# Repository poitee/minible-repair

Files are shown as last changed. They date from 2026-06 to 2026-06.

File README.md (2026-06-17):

# Mooltipass Mini BLE repair project

Community guides and printable parts to extend the life of a Mini BLE.

## Contents

| Path | Description |
|---|---|
| [battery/BOM.md](battery/BOM.md) | Replacement cell specifications and sourcing notes |
| [battery/replacement.md](battery/replacement.md) | Step-by-step battery swap procedure |
| [case/minible-shell.scad](case/minible-shell.scad) | Parametric service shell (OpenSCAD) |
| [case/stl/](case/stl/) | **Print-ready STL files** (top, bottom, battery door) |
| [case/README.md](case/README.md) | How to export STLs and assemble the shell |
| [case/print-settings.md](case/print-settings.md) | Suggested slicer settings |
| [docs/dimensions.md](docs/dimensions.md) | KiCad-derived mechanical reference |
| [docs/teardown.md](docs/teardown.md) | Case opening notes and internal layout |
| [tools/extract_kicad_dims.py](tools/extract_kicad_dims.py) | Regenerate feature coordinates from KiCad |

## Quick links

**Replace the battery** → start with [battery/BOM.md](battery/BOM.md)

**Print a service shell** → [case/README.md](case/README.md)

**Open the factory case** → [docs/teardown.md](docs/teardown.md)

## Important safety notes

- The Mini BLE uses a **NiMH** cell, not LiPo. Do not install a lithium cell.
- The stock cell is soldered to the PCB. Replacement requires soldering skills.
- Opening the factory aluminum shell may damage it. Treat this project as a **repair path**, not a drop-in factory replacement.
- You are responsible for safe handling of batteries and ESD-sensitive electronics.

## Device reference dimensions

Published external size: **89.0 × 35.5 × 12.5 mm** (L × W × H).

PCB outline from [minible_hw](https://github.com/mooltipass/minible_hw): **74.8 × 31.2 mm**.

Battery: **2/3 AAA NiMH**, ~300 mAh (`BAT_TWOTHIRD_AAA`).

Full coordinate table: [docs/dimensions.md](docs/dimensions.md).

## Status

Community draft — fit has not been validated on physical hardware yet. If you print the shell or complete a battery swap, please share caliper measurements and photos.

## Contributing

See [CONTRIBUTING.md](CONTRIBUTING.md).

## License

MIT — see [LICENSE](LICENSE).

## Related upstream projects

- [mooltipass/minible](https://github.com/mooltipass/minible) — firmware
- [mooltipass/minible_hw](https://github.com/mooltipass/minible_hw) — hardware design files
- [mooltipass/moolticute](https://github.com/mooltipass/moolticute) — desktop companion

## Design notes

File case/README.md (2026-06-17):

# Case parts

Parametric OpenSCAD shell for servicing a Mini BLE after the factory aluminum case is opened or damaged.

## Files

| File | Description |
|---|---|
| `minible-shell.scad` | Source model — edit parameters here |
| `export-stl.sh` | Headless STL export |
| `stl/` | Generated meshes (after export) |
| `print-settings.md` | Suggested slicer settings |

## Quick start

**Pre-built STLs** are in [`case/stl/`](stl/) — ready to slice.

To regenerate after editing `minible-shell.scad` or `tools/generate_stl.py`:

```bash
pip3 install -r tools/requirements.txt
./case/export-stl.sh
```

Or only:

```bash
python3 tools/generate_stl.py
```

OpenSCAD is optional (see `minible-shell.scad` for parametric edits); STL export uses Python + [trimesh](https://github.com/mikedh/trimesh).

This writes:

- `case/stl/minible-shell-top.stl` — display face + scroll wheel bore
- `case/stl/minible-shell-bottom.stl` — USB-C, smartcard slot, battery pocket
- `case/stl/minible-battery-door.stl` — optional cover for battery pocket

## Assembly

1. Print top and bottom shells (see `print-settings.md`).
2. Dry-fit the PCB without the battery.
3. Route the OLED flex cable before closing the shell.
4. Join halves with four M2 screws through J1/J2 standoff posts (length depends on print — start with 8–10 mm).
5. Optionally tape or screw the battery door over the access pocket.

## Tuning fit

Open `minible-shell.scad` and adjust:

- `clearance` — global PCB pocket tolerance (default 0.4 mm)
- `usb_open_*` — USB cutout size
- `wheel_bore_d` — scroll wheel clearance
- `battery_door_*` — under-cell access opening

After changing parameters tied to KiCad, update `docs/dimensions.md` and note your caliper measurements in the pull request.

## Orientation preview

In OpenSCAD, set `part = "both"` to preview top + bottom + battery door layouts side by side.

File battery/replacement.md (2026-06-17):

# Battery replacement procedure

## Before you start

- Read [BOM.md](BOM.md) and confirm you have a **tagged 2/3 AAA NiMH** cell.
- Export your credentials from Moolticute if you have not recently backed up.
- Work on an ESD-safe surface.
- Expect to **open or replace the outer shell** — see [../docs/teardown.md](../docs/teardown.md).

## Discharge handling

If the old cell still holds charge, avoid shorting the tabs. Insulate removed cell terminals with tape.

## Removal

1. Open the device enclosure and expose the main PCB.
2. Note pad polarity — photograph the original orientation.
3. Apply flux to both battery pads.
4. Heat each pad in turn and lift the cell free with minimal force on the tabs.
5. Remove residual solder from pads if needed so the new tabs sit flat.

## Installation

1. Match the **positive tab** to the pad marked `BAT+` on the [PSU schematic](https://github.com/mooltipass/minible_hw/blob/master/main_board/mini_ble_psu.sch).
2. Tack one tab, verify alignment, then solder the second tab.
3. Avoid excessive heat — work quickly and let the cell cool between attempts.
4. Visually inspect joints under good light.

## Reassembly and validation

1. Route the OLED flex cable carefully — it is easy to damage ([minible_hw#4](https://github.com/mooltipass/minible_hw/issues/4)).
2. Reinstall the PCB in your shell (factory aluminum or [printed service shell](../case/minible-shell.scad)).
3. Connect USB:
   - Device should enumerate normally.
   - Leave on charge until the firmware reports a full state.
4. Unplug USB and confirm:
   - Power-on via scroll wheel click
   - Stable operation for at least several minutes
   - Reasonable battery indicator behavior

## Troubleshooting

| Symptom | Likely cause |
|---|---|
| Works on USB only | Weak/counterfeit cell, cold solder joint, reversed polarity |
| Rapid shutdown after unplug | Cell not actually charged, high self-discharge cell |
| Overheating on charge | Wrong chemistry installed — **stop and disconnect** |

## Firmware notes

The Mini BLE firmware includes a custom NiMH charging routine. There is no documented “battery pairing” or anti-replacement lock — failures are almost always hardware-related.

For persistent issues after verifying a known-good cell, open a discussion in this repo with photos of the solder joints (not your credentials).

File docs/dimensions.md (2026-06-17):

# Mechanical dimensions

Values below are derived from [mooltipass/minible_hw](https://github.com/mooltipass/minible_hw) `main_board/mini_ble.kicad_pcb` and published retail specifications.

Regenerate `dimensions.json`:

```bash
python3 tools/update_dimensions.py
```

## Envelope

| Item | mm |
|---|-----|
| Retail case (L × W × H) | 89.0 × 35.5 × 12.5 |
| Main PCB (L × W) | 74.8 × 31.2 |
| PCB inset margin (X / Y) | 7.1 / 2.15 |

## Coordinate system (case)

- Origin: bottom-left-back corner
- **+X** → scroll wheel end
- **+Y** → smartcard edge
- **+Z** → display face

## Feature positions (case coordinates)

| Feature | X | Y | Notes |
|---|---|---|---|
| USB-C | 72.9 | 5.35 | GT-USB-7010 receptacle |
| Scroll wheel | 78.4 | 17.75 | SRBE210200 |
| OLED center | 41.4 | 17.75 | ~52 × 14 mm window (active area — verify) |
| Smartcard | 19.0 | 29.3 | Slot on +Y edge |
| Battery BT1 | 7.4 | 17.75 | 2/3 AAA NiMH, soldered |
| Mount J1 | 9.6 | 3.75 | M1.4 |
| Mount J2 | 9.6 | 31.75 | M1.4 |

## Battery cell

| Property | Value |
|---|---|
| Footprint | `BAT_TWOTHIRD_AAA` |
| Chemistry | NiMH |
| Capacity | ~300 mAh |
| Pad spacing | 20.6 mm center-to-center |

## Still verify on hardware

- PCB stack height (`pcb_h` in OpenSCAD, default 6.0 mm)
- OLED visible area vs. bezel overlap
- USB-C recess depth for your cable shell
- Factory aluminum shell internal ribs (not modeled in KiCad)

## References

- [FCC internal photos (MBLE1)](https://fccid.io/2AYPT-MBLE1/Internal-Photos/Internal-Photos-5088688)
- [minible_hw#4 — battery disconnect switch request](https://github.com/mooltipass/minible_hw/issues/4)

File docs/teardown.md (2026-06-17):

# Teardown notes

## Factory enclosure

The retail Mini BLE uses a **brushed aluminum** shell approximately **89 × 35.5 × 12.5 mm**. The factory assembly is not designed for end-user service. Expect:

- Adhesive or tight snap fits
- Risk of cosmetic damage when opening
- No standard screws on most units

Community contributors should document their opening method here once validated. If you succeed with a repeatable technique, add photos via pull request.

## Internal layout (from open hardware files)

Reference repository: [mooltipass/minible_hw](https://github.com/mooltipass/minible_hw)

| Item | Notes |
|---|---|
| Main PCB outline | 74.8 × 31.2 mm (Edge.Cuts bounding box) |
| Battery `BT1` | 2/3 AAA NiMH, soldered (`BAT_TWOTHIRD_AAA`) |
| Display | OLED module with fragile flex cable |
| USB-C | Board edge connector |
| Scroll wheel | Mechanical assembly on front face |
| Smartcard slot | End of device |

## FCC internal photos

Stephan Electronics filed internal photos for model **MBLE1**:

https://fccid.io/2AYPT-MBLE1/Internal-Photos/Internal-Photos-5088688

Use these photos together with the KiCad PCB to confirm component keep-out zones before printing a service shell.

## Recommended service approach

1. Open or sacrifice the factory shell once.
2. Take **caliper measurements** of:
   - PCB-to-shell clearance (top/bottom/sides)
   - Display active area and bezel overlap
   - USB-C port centerline and panel thickness
   - Scroll wheel bore diameter and exposed height
3. Compare against [dimensions.md](dimensions.md) and tune [minible-shell.scad](../case/minible-shell.scad).
4. Install the PCB in the printed **service shell** for future battery access.

## Opening techniques (community draft)

The stock shell is aluminum and not designed for user service. Approaches reported in similar devices:

| Method | Risk | Notes |
|---|---|---|
| Plastic spudger along seam | Cosmetic scratches | Work slowly around the perimeter |
| Heat gun + isopropyl on adhesive | Warping / burn risk | Low heat only; keep away from battery |
| Sacrifice rear panel | Lose waterproofing | Acceptable if moving to printed shell |

> **We need community validation.** If you successfully open a unit, please document your method with photos in a pull request.

## Assembly orientation

When viewing the device with the **display facing up** and the **scroll wheel to your right**:

- USB-C is on the bottom edge near the wheel end
- Smartcard slot is on the top edge near the battery end
- Battery cell sits under the left end of the PCB

## Battery service constraint

The stock design routes battery replacement through **desoldering** because there is no inline disconnect switch ([minible_hw#4](https://github.com/mooltipass/minible_hw/issues/4)). Plan for full PCB removal or a shell that allows bottom access.

## ESD and cleanliness

The secure MCU and smartcard interface are ESD-sensitive. Avoid metal tools near powered flex cables.

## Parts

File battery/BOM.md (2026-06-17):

# Mini BLE replacement battery — BOM

## Required cell

| Property | Value | Source |
|---|---|---|
| Chemistry | **NiMH** | [minible_hw](https://github.com/mooltipass/minible_hw) schematic (`BT1`) |
| Form factor | **2/3 AAA** | KiCad footprint `BAT_TWOTHIRD_AAA` |
| Nominal capacity | **~300 mAh** | [product specs](https://www.themooltipass.com) |
| Terminals | Solder tabs | Stock cell is through-hole soldered to PCB |

### Pad spacing (from KiCad footprint)

- Center-to-center between pads: **20.6 mm**
- Pad size: 4 × 3 mm oval holes

### Typical 2/3 AAA NiMH dimensions

| Dimension | Typical range |
|---|---|
| Diameter | 10.0 – 10.5 mm |
| Height (without tabs) | 30.0 – 31.0 mm |

Always measure your replacement cell before soldering.

## What **not** to use

- **LiPo / Li-ion cells** — charging circuitry implements a custom **NiMH** algorithm in firmware.
- **NiCd** — different charge profile; not validated on this hardware.
- Cells without reliable capacity ratings or unknown age (see [minible#422](https://github.com/mooltipass/minible/issues/422)).

## Example part categories

Search distributors for:

- `2/3 AAA NiMH 300mAh solder tabs`
- `2/3 AAA NiMH tagged`

Brands commonly used in tagged NiMH packs: Tenergy, Powerex, generic industrial tagged cells.

> Supplier links intentionally omitted — availability varies by region. Validate diameter and tab orientation against the original cell before ordering multiple units.

## Tools and consumables

- Temperature-controlled soldering iron (fine tip)
- Flux and lead-free solder
- Kapton tape
- ESD mat / wrist strap
- Plastic spudgers
- Multimeter (verify polarity and idle voltage after install)

## After installation

1. Inspect for solder bridges on battery pads.
2. Reassemble the device.
3. Connect USB and confirm the device boots.
4. In Moolticute, run **battery reconditioning** if available for your firmware bundle.
5. Disconnect USB and verify the device runs on battery power.

If the device only works on USB, the cell may be dead, reversed, or poorly soldered — not a firmware “security lock” ([#422](https://github.com/mooltipass/minible/issues/422)).

## Future hardware improvement

Upstream feature request: inline battery disconnect switch — [minible_hw#4](https://github.com/mooltipass/minible_hw/issues/4).

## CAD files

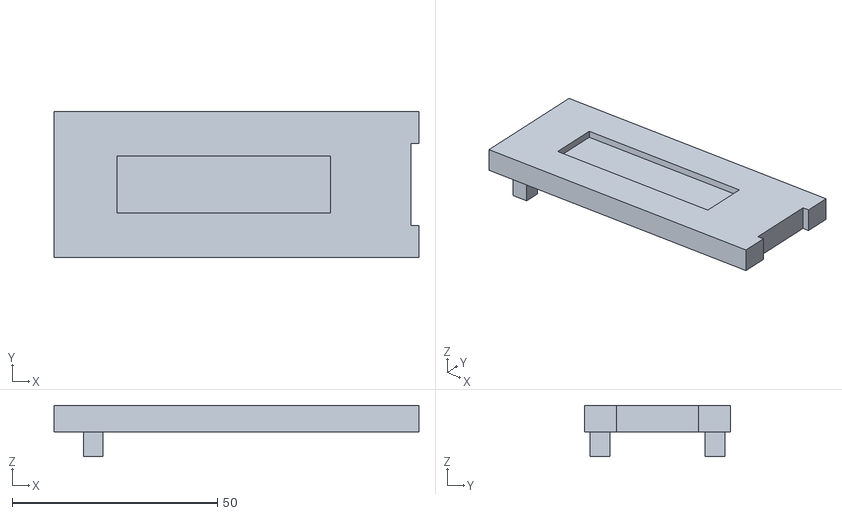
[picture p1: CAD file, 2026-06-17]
case/stl/minible-shell-top.stl
89.0 x 35.5 x 12.5

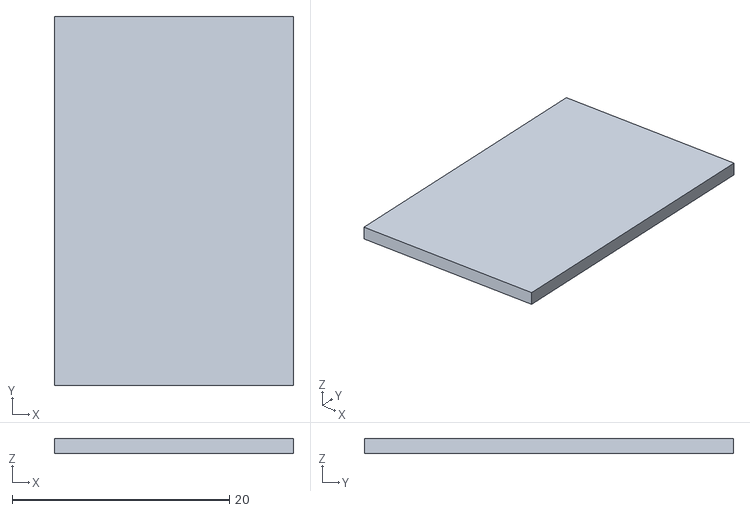
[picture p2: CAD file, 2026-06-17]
case/stl/minible-battery-door.stl
22.0 x 34.0 x 1.40

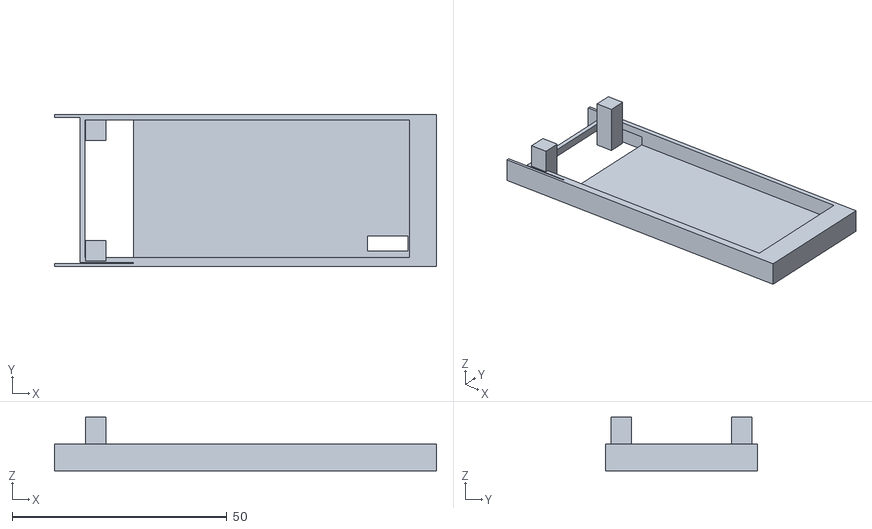
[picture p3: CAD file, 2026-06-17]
case/stl/minible-shell-bottom.stl
89.0 x 35.5 x 12.5

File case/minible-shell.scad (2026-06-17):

// Mooltipass Mini BLE — service shell (two-part clam shell)
// Coordinate system: origin at bottom-left-back corner of the case.
//   +X = toward scroll wheel end (89 mm)
//   +Y = toward smartcard edge (35.5 mm)
//   +Z = toward display face (12.5 mm)
//
// Dimensions derived from minible_hw KiCad (see docs/dimensions.md).
// Run: ./case/export-stl.sh

part = "both";          // "front" | "back" | "both" | "battery_door"

// --- case envelope ---
case_l = 89.0;
case_w = 35.5;
case_h = 12.5;
wall = 1.8;
clearance = 0.4;
corner_r = 3.0;

// --- PCB pocket ---
pcb_l = 74.8;
pcb_w = 31.2;
pcb_h = 6.0;            // verify stack height on hardware
margin_x = (case_l - pcb_l) / 2;   // 7.1
margin_y = (case_w - pcb_w) / 2;   // 2.15

// --- feature positions (case coords, mm) ---
usb_x = 72.9;
usb_y = 5.35;
usb_open_w = 9.5;
usb_open_h = 3.5;

wheel_x = 78.4;
wheel_y = 17.75;
wheel_bore_d = 20.0;

oled_cx = 41.4;         // approx. center of 52 mm active area
oled_cy = 17.75;
oled_w = 52.0;
oled_h = 14.0;

card_x = 4.0;
card_y = 29.3;
card_slot_w = 24.0;
card_slot_h = 1.4;

battery_cx = 7.4;
battery_cy = 17.75;
battery_door_w = 22.0;
battery_door_h = 34.0;

mount_j1 = [9.6, 3.75];
mount_j2 = [9.6, 31.75];
mount_d = 1.6;          // M1.4 screw clearance

lip_depth = 2.0;
lip_inset = 1.2;
split_gap = 0.25;
screw_post_d = 4.8;

inner_l = pcb_l + 2 * clearance;
inner_w = pcb_w + 2 * clearance;
inner_h = pcb_h + clearance;

module rounded_box(l, w, h, r) {
    // Simple chamfered box — avoids heavy minkowski() in headless export.
    cube([l, w, h]);
}

module pcb_cavity() {
    translate([margin_x, margin_y, wall])
        cube([inner_l, inner_w, inner_h]);
}

module usb_port() {
    translate([usb_x, usb_y - usb_open_h / 2, -0.1])
        cube([usb_open_w, usb_open_h, wall + 0.2]);
}

module wheel_bore() {
    translate([case_l - wall - 0.1, wheel_y - wheel_bore_d / 2, case_h / 2 - wheel_bore_d / 2])
        cube([wall + 0.2, wheel_bore_d, wheel_bore_d]);
}

module display_window() {
    translate([oled_cx - oled_w / 2, oled_cy - oled_h / 2, case_h - wall - 0.1])
        cube([oled_w, oled_h, wall + 0.2]);
}

module card_slot() {
    translate([card_x, card_y - card_slot_w / 2, case_h / 2 - card_slot_h / 2])
        cube([wall + 2, card_slot_w, card_slot_h + 0.2]);
}

module mount_posts() {
    for (p = [mount_j1, mount_j2])
        translate([p[0] - screw_post_d / 2, p[1] - screw_post_d / 2, 0])
            cube([screw_post_d, screw_post_d, case_h]);
}

module mount_holes() {
    for (p = [mount_j1, mount_j2])
        translate([p[0] - mount_d / 2, p[1] - mount_d / 2, -0.1])
            cube([mount_d, mount_d, case_h + 0.2]);
}

module mating_lip(top = true) {
    z0 = top ? case_h / 2 : case_h / 2 - lip_depth;
    translate([margin_x - lip_inset, margin_y - lip_inset, z0])
        difference() {
            cube([inner_l + 2 * lip_inset, inner_w + 2 * lip_inset, lip_depth]);
            translate([lip_inset, lip_inset, -0.1])
                cube([inner_l, inner_w, lip_depth + 0.2]);
        }
}

module top_shell() {
    intersection() {
        difference() {
            rounded_box(case_l, case_w, case_h, corner_r);
            pcb_cavity();
            display_window();
            wheel_bore();
            mount_holes();
        }
        translate([-0.1, -0.1, case_h / 2 - split_gap])
            cube([case_l + 0.2, case_w + 0.2, case_h / 2 + split_gap]);
    }
    mating_lip(true);
    mount_posts();
}

module bottom_shell() {
    intersection() {
        difference() {
            rounded_box(case_l, case_w, case_h, corner_r);
            pcb_cavity();
            usb_port();
            card_slot();
            mount_holes();
            battery_access_cut();
        }
        translate([-0.1, -0.1, -0.1])
            cube([case_l + 0.2, case_w + 0.2, case_h / 2 + split_gap]);
    }
    mating_lip(false);
    mount_posts();
}

module battery_access_cut() {
    // Pocket under BT1 for future swaps without splitting the whole shell.
    translate([battery_cx - battery_door_w / 2, battery_cy - battery_door_h / 2, -0.1])
        cube([battery_door_w, battery_door_h, wall + inner_h + 0.5]);
}

module battery_door() {
  t = 1.4;
  translate([battery_cx - battery_door_w / 2, battery_cy - battery_door_h / 2, wall - 0.05])
    cube([battery_door_w, battery_door_h, t]);
}

if (part == "front" || part == "top") {
    top_shell();
} else if (part == "back" || part == "bottom") {
    bottom_shell();
} else if (part == "battery_door") {
    battery_door();
} else {
    color("Gainsboro") top_shell();
    translate([0, case_w + 6, 0]) color("DimGray") bottom_shell();
    translate([0, 2 * (case_w + 6), 0]) color("Silver") battery_door();
}

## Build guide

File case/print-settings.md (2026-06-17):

# Print settings

## Recommended material

| Material | Notes |
|---|---|
| **PETG** | Good durability, moderate heat resistance — good default |
| **ASA** | Better heat resistance near USB-C port area |
| **PLA** | Acceptable for prototyping; may creep in warm environments |

## Suggested parameters (starting point)

| Setting | Value |
|---|---|
| Layer height | 0.2 mm |
| Perimeters | 3–4 |
| Infill | 20–25 % gyroid or grid |
| Horizontal expansion | 0 – 0.1 mm (tune fit) |
| Support | Usually none if printing shells upright |

## Orientation

Print each half **flat on the split face** so the mating flange is accurate.

## Post-processing

- Test-fit the PCB without the battery installed.
- Open the USB-C slot with a file if your printer tolerances are loose.
- Dry-fit the scroll wheel bore before gluing anything.

## Fit validation checklist

- [ ] PCB drops in without bowing
- [ ] USB-C plug inserts fully
- [ ] OLED window aligns with display active area
- [ ] Scroll wheel rotates without rubbing
- [ ] Halves close without flexing the PCB
- [ ] Smartcard inserts cleanly

Mark any parameter tweaks in a pull request with your measured values.

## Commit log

2026-06-17 Initial Mini BLE repair kit: battery docs and service shell
    Document NiMH battery replacement, KiCad-derived mechanical dimensions,
    and a parametric OpenSCAD clam-shell with battery access pocket.
    [minible-shell.scad]
2026-06-17 Validate KiCad PCB path in dimension extraction tool
2026-06-17 Add print-ready STL files and Python STL generator
    Ship top shell, bottom shell, and battery door STLs in case/stl/.
    Replace broken OpenSCAD-only export with tools/generate_stl.py (trimesh).
    [minible-battery-door.stl, minible-shell-bottom.stl, minible-shell-top.stl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]
